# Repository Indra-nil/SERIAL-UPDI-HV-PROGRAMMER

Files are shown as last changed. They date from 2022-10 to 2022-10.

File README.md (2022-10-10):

# Serial UPDI HV Programmer
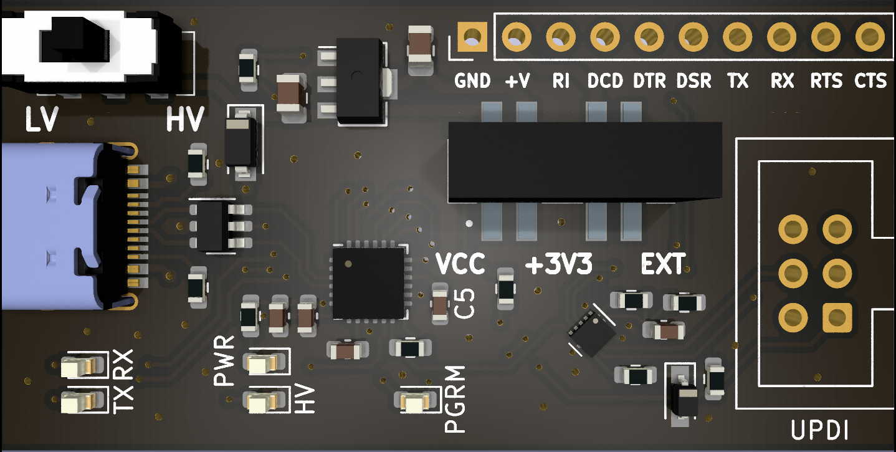
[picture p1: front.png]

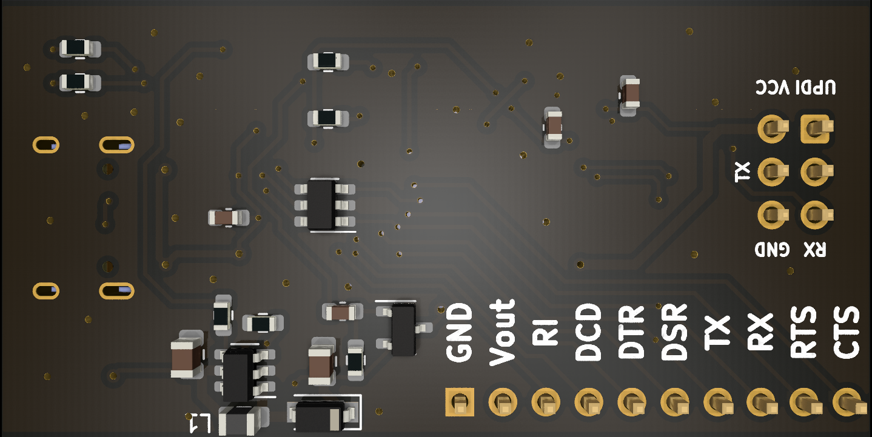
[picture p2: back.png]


Serial UPDI HV Programmer for new AVR ICs using Silabs CP2105 IC. Because of having two UART core one is dedicated to UPDI and another is for Serial communication. No need for two seperate usb port for two UART anymore.

when Vcc selected Vout nearly 4.7v

when +3.3v selected Vout 3.3v

when EXT selected Vout external voltage from target board

Some useful links
--------------------

[pyupdi](https://github.com/mraardvark/pyupdi.git)

[MegaCoreX(arduino core)](https://github.com/MCUdude/MegaCoreX.git)

[megaTinyCore(arduino core)](https://github.com/SpenceKonde/megaTinyCore.git)

[DxCore(arduino core)](https://github.com/SpenceKonde/DxCore.git)

[TinyCore(arduino core)](https://github.com/xukangmin/TinyCore.git)

[Microchip Studio for AVR](https://www.microchip.com/en-us/tools-resources/develop/microchip-studio)

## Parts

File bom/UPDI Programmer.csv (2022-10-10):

Source: | /home/indra/Documents/KiCad/UPDI Programmer/UPDI Programmer.kicad_sch
Date: | Mon 10 Oct 2022 01:49:07 PM IST
Tool: | Eeschema 6.0.6
Generator: | /app/share/kicad/plugins/bom_csv_grouped_by_value_with_fp.py
Component Count: | 51
Ref | Qnty | Value | Cmp name | Footprint | Description | Vendor
C1, C11, C13, | 3 | 1u | C | Capacitor_SMD:C_0603_1608Metric | Unpolarized capacitor
C2, C3, C9, C12, | 4 | 100n | C | Capacitor_SMD:C_0603_1608Metric | Unpolarized capacitor
C4, C7, C8, C10, | 4 | 10u | C | Capacitor_SMD:C_0805_2012Metric | Unpolarized capacitor
C5, | 1 | 4u7 | C | Capacitor_SMD:C_0603_1608Metric | Unpolarized capacitor
C6, | 1 | 10n | C | Capacitor_SMD:C_0603_1608Metric | Unpolarized capacitor
D1, D5, | 2 | 1N5819W | BAT43W-V | Diode_SMD:D_SOD-123 | 30V 0.2A Small Signal Schottky diode, SOD-123
D2, | 1 | TX | LED | LED_SMD:LED_0603_1608Metric | Light emitting diode
D3, | 1 | RX | LED | LED_SMD:LED_0603_1608Metric | Light emitting diode
D4, | 1 | PWR | LED | LED_SMD:LED_0603_1608Metric | Light emitting diode
D6, | 1 | PGRM | LED | LED_SMD:LED_0603_1608Metric | Light emitting diode
D7, | 1 | HV | LED | LED_SMD:LED_0603_1608Metric | Light emitting diode
D8, | 1 | BZT52Bxx | BZT52Bxx | Diode_SMD:D_SOD-323_HandSoldering | 500mW Zener Diode, SOD-123F
J1, | 1 | USB_C_Receptacle_USB2.0 | USB_C_Receptacle_USB2.0 | HRO_TYPE-C-31-M-12:HRO_TYPE-C-31-M-12 | USB 2.0-only Type-C Receptacle connector
J2, | 1 | UPDI | Conn_02x03_Odd_Even | Connector_IDC:IDC-Header_2x03_P2.54mm_Vertical | Generic connector, double row, 02x03, odd/even pin numbering scheme (row 1 odd numbers, row 2 even numbers), script generated (kicad-library-utils/schlib/autogen/connector/)
J3, | 1 | UART | Conn_01x10 | Connector_PinHeader_2.54mm:PinHeader_1x10_P2.54mm_Vertical | Generic connector, single row, 01x10, script generated (kicad-library-utils/schlib/autogen/connector/)
L1, | 1 | 4u7 | L | Inductor_SMD:L_0805_2012Metric | Inductor
Q1, | 1 | BSS84 | BSS84 | Package_TO_SOT_SMD:SOT-23 | -0.13A Id, -50V Vds, P-Channel MOSFET, SOT-23
R1, R4, | 2 | 4k7 | R | Resistor_SMD:R_0603_1608Metric | Resistor
R2, R3, | 2 | 5k1 | R | Resistor_SMD:R_0603_1608Metric | Resistor
R5, R13, | 2 | 10k | R | Resistor_SMD:R_0603_1608Metric | Resistor
R6, | 1 | 220 | R | Resistor_SMD:R_0603_1608Metric | Resistor
R7, R8, R9, R12, R14, R15, R16, R17, | 8 | 1k | R | Resistor_SMD:R_0603_1608Metric | Resistor
R10, | 1 | 39k | R | Resistor_SMD:R_0603_1608Metric | Resistor
R11, | 1 | 2k05 | R | Resistor_SMD:R_0603_1608Metric | Resistor
S1, | 1 | JS203011SCQN | JS203011SCQN | JS203011SCQN:JS203011SCQN
S2, | 1 | JS202011JCQN | JS202011JCQN | JS202011JCQN:JS202011JCQN
U1, | 1 | CP2105-F01-GM | CP2105-F01-GM | CP2105-F01-GM:CP2105-F01-GM
U2, | 1 | USBLC6-2SC6 | USBLC6-2SC6 | Package_TO_SOT_SMD:SOT-23-6 | Very low capacitance ESD protection diode, 2 data-line, SOT-23-6
U3, | 1 | AMS1117-3.3 | AMS1117-3.3 | Package_TO_SOT_SMD:SOT-89-3 | 1A Low Dropout regulator, positive, 3.3V fixed output, SOT-223
U4, | 1 | 74LVC2G04DVBR | 74LVC2G04 | Package_TO_SOT_SMD:SOT-23-6 | Dual NOT Gate, Low-Voltage CMOS
U5, | 1 | MT3608 | MT3608 | Package_TO_SOT_SMD:SOT-23-6 | High Efficiency 1.2MHz 2A Step Up Converter, 2-24V Vin, 28V Vout, 4A current limit, 1.2MHz, SOT23-6
U6, | 1 | TXB0104RUT | TXB0104RUT | Package_DFN_QFN:Texas_R_PUQFN-N12 | 4-Bit Bidirectional Voltage-Level Translator, Auto Direction Sensing and ±15-kV ESD Protection, 1.2 - 3.6V APort, 1.65 - 5.5V BPort, Texas_PUQFN-12

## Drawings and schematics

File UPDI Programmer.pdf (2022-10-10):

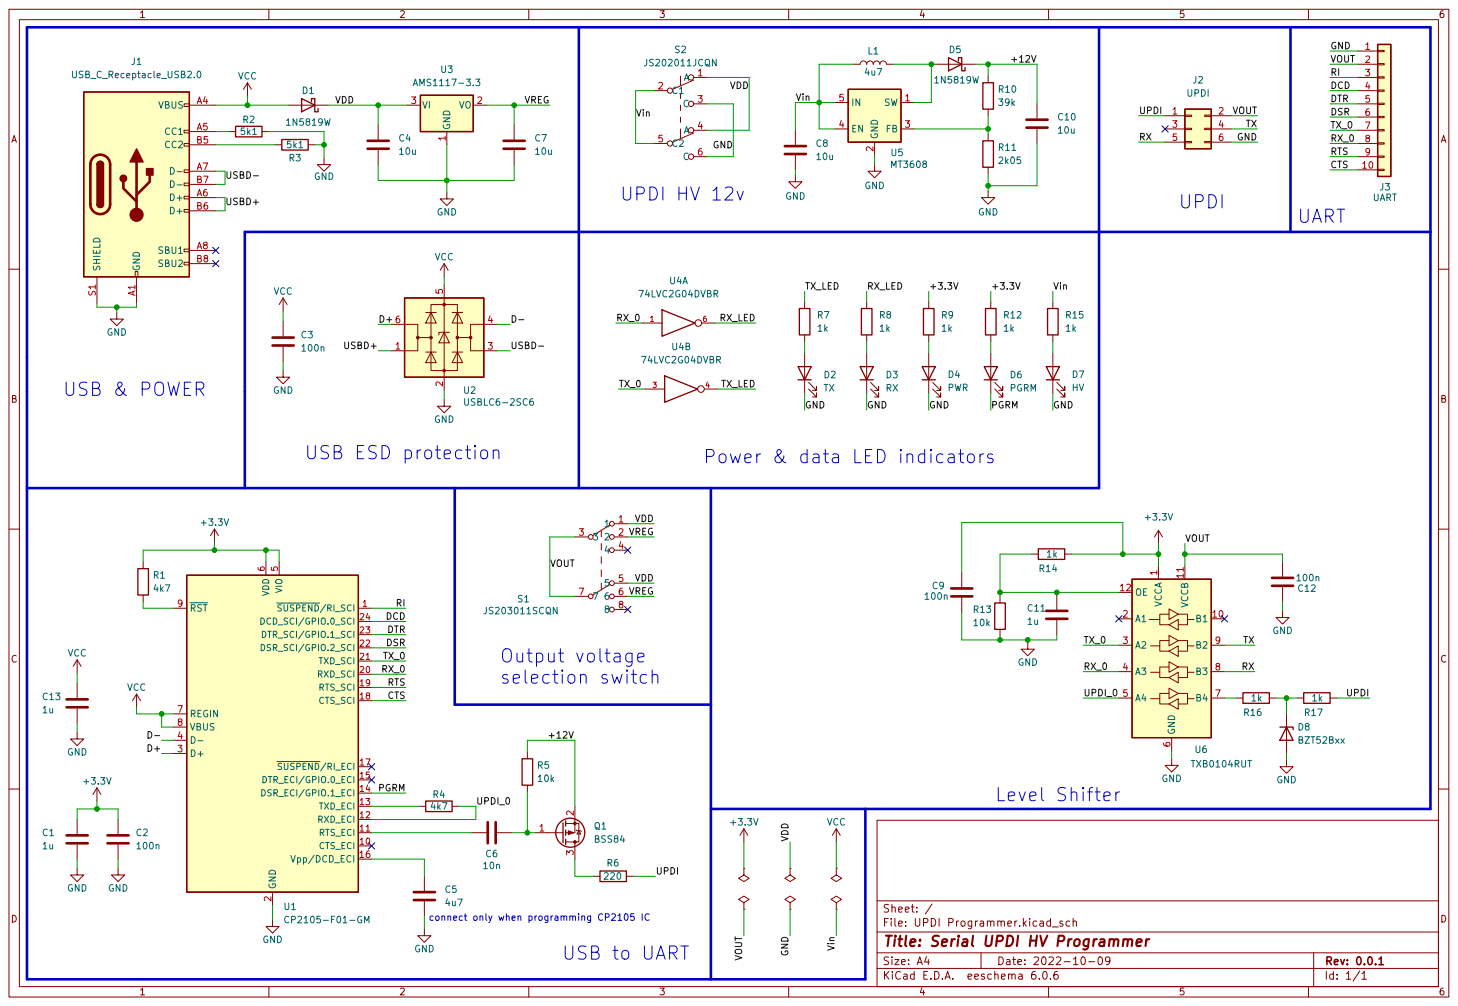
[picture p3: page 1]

Power & data LED indicators

6 REGIN 7 VBUS 8 ~{RST} 9 U1CP2105-F01-GM

2 RXD_SCI 20 TXD_SCI 21 DSR_SCI/GPIO.2_SCI 22 DTR_SCI/GPIO.1_SCI 23 DCD_SCI/GPIO.0_SCI 24 D+ 3 D- 4 VIO

File: UPDI Programmer.kicad_sch Sheet: /
Id: 1/1 Title: Serial UPDI HV Programmer

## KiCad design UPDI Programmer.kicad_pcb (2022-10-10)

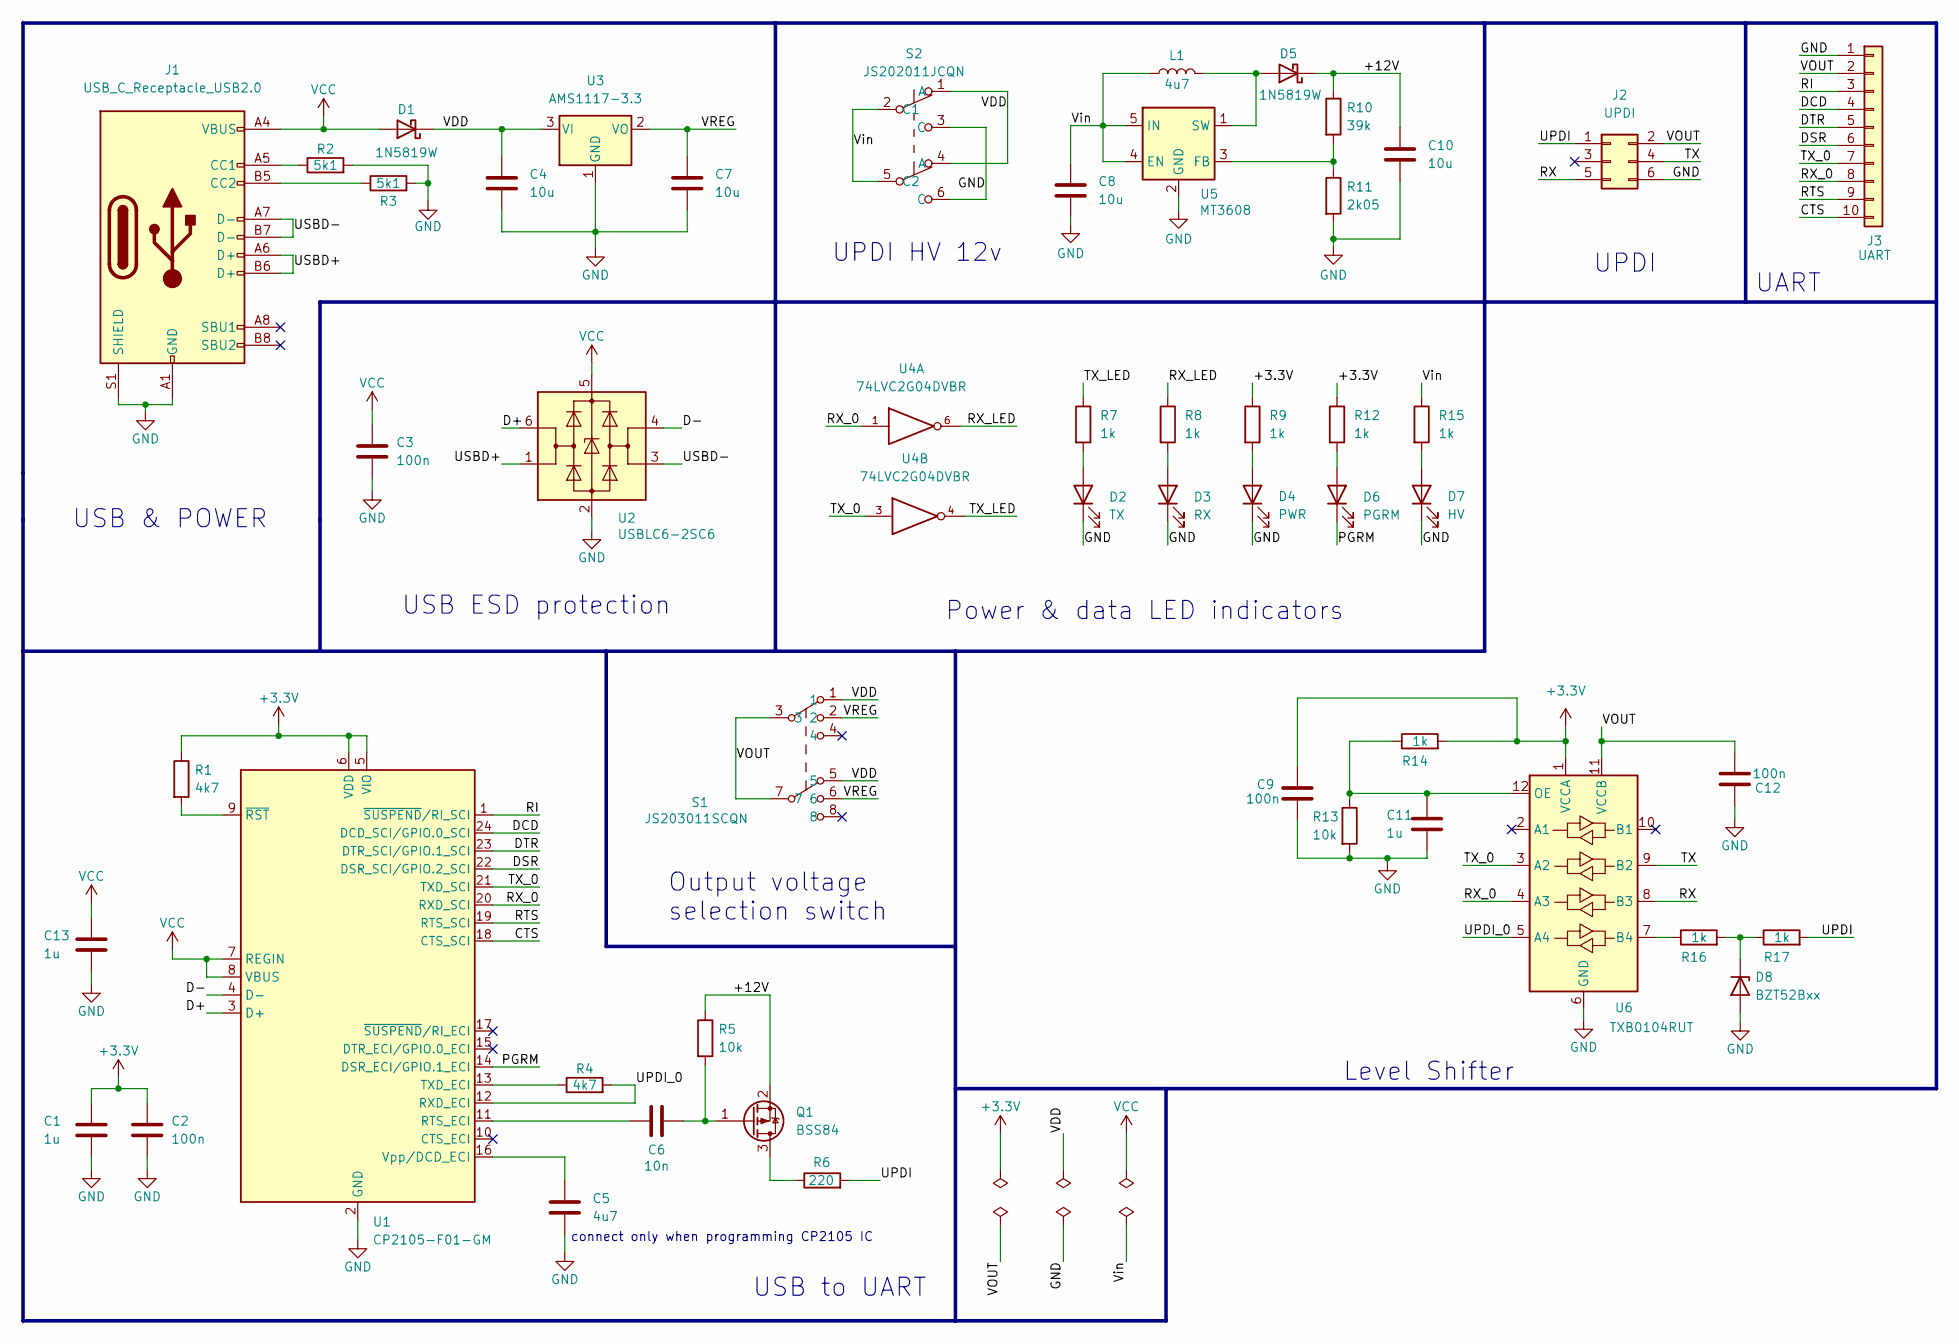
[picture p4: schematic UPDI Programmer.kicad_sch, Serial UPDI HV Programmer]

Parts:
C1, C11, C13: 1u; C_0603_1608Metric
C2, C3, C9, C12: 100n; C_0603_1608Metric
C4, C7, C8, C10: 10u; C_0805_2012Metric
C5: 4u7; C_0603_1608Metric
C6: 10n; C_0603_1608Metric
D1, D5: 1N5819W; D_SOD-123
D2: TX; LED_0603_1608Metric
D3: RX; LED_0603_1608Metric
D4: PWR; LED_0603_1608Metric
D6: PGRM; LED_0603_1608Metric
D7: HV; LED_0603_1608Metric
D8: BZT52Bxx; D_SOD-323_HandSoldering
J1: USB_C_Receptacle_USB2.0; HRO_TYPE-C-31-M-12
J2: UPDI; IDC-Header_2x03_P2.54mm_Vertical
J3: UART; PinHeader_1x10_P2.54mm_Vertical
L1: 4u7; L_0805_2012Metric
Q1: BSS84; SOT-23
R1, R4: 4k7; R_0603_1608Metric
R2, R3: 5k1; R_0603_1608Metric
R5, R13: 10k; R_0603_1608Metric
R6: 220; R_0603_1608Metric
R7, R8, R9, R12, R14, R15, R16, R17: 1k; R_0603_1608Metric
R10: 39k; R_0603_1608Metric
R11: 2k05; R_0603_1608Metric
S1: JS203011SCQN; Manufacturer_Part_Number JS203011SCQN; Mouser Part Number 611-JS203011SCQN
S2: JS202011JCQN; Manufacturer_Part_Number JS202011JCQN; Mouser Part Number 611-JS202011JCQN
U1: CP2105-F01-GM; Manufacturer_Part_Number CP2105-F01-GM
U2: USBLC6-2SC6; SOT-23-6
U3: AMS1117-3.3; SOT-89-3
U4: 74LVC2G04DVBR; SOT-23-6
U5: MT3608; SOT-23-6
U6: TXB0104RUT; Texas_R_PUQFN-N12

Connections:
+3.3V: C1.1, C2.1, C9.2, R1.1, R9.1, R12.1, R14.2, U1.5 (VIO), U1.6 (VDD), U6.1 (VCCA)
/+12V: C10.1, D5.1 (K), Q1.2 (S), R5.1, R10.1
/CTS: J3.10, U1.18 (CTS_SCI)
/D+: U1.3 (D+), U2.6 (I/O1)
/D-: U1.4 (D-), U2.4 (I/O2)
/DCD: J3.4, U1.24 (DCD_SCI/GPIO.0_SCI)
/DSR: J3.6, U1.22 (DSR_SCI/GPIO.2_SCI)
/DTR: J3.5, U1.23 (DTR_SCI/GPIO.1_SCI)
/PGRM: D6.1 (K), U1.14 (DSR_ECI/GPIO.1_ECI)
/RI: J3.3, U1.1 (~SUSPEND/RI_SCI)
/RTS: J3.9, U1.19 (RTS_SCI)
/RX: J2.5, U6.8 (B3)
/RX_0: J3.8, U1.20 (RXD_SCI), U4.1, U6.4 (A3)
/RX_LED: R8.1, U4.6
/TX: J2.4, U6.9 (B2)
/TX_0: J3.7, U1.21 (TXD_SCI), U4.3, U6.3 (A2)
/TX_LED: R7.1, U4.4
/UPDI: J2.1, R6.2, R17.2
/UPDI_0: R4.2, U1.12 (RXD_ECI), U6.5 (A4)
/USBD+: J1.A6 (D+), J1.B6 (D+), U2.1 (I/O1)
/USBD-: J1.A7 (D-), J1.B7 (D-), U2.3 (I/O2)
/VDD: C4.1, D1.1 (K), S1.1, S1.5, S2.1 (A), S2.4 (A), U3.3 (VI)
/VOUT: C12.1, J2.2, J3.2, S1.3, S1.7, U6.11 (VCCB)
/VREG: C7.1, S1.2, S1.6, U3.2 (VO)
/Vin: C8.1, L1.1, R15.1, S2.2 (C1), S2.5 (C2), U5.4 (EN), U5.5 (IN)
GND: C1.2, C2.2, C3.2, C4.2, C5.2, C7.2, C8.2, C9.1, C10.2, C11.1, C12.2, C13.2, D2.1 (K), D3.1 (K), D4.1 (K), D7.1 (K), D8.2 (A), J1.A1 (GND), J1.A12 (GND), J1.B1 (GND), J1.B12 (GND), J1.S1 (SHIELD), J2.6, J3.1, R2.2, R3.2, R11.2, R13.2, S2.3 (C), S2.6 (C), U1.2 (GND), U1.25 (GND), U2.2 (GND), U3.1 (GND), U4.2 (GND), U5.2 (GND), U6.6 (GND)
unnamed: C5.1, U1.16 (Vpp/DCD_ECI)
unnamed: C6.1, U1.11 (RTS_ECI)
unnamed: C6.2, Q1.1 (G), R5.2
unnamed: C11.2, R13.1, R14.1, U6.12 (OE)
unnamed: D2.2 (A), R7.2
unnamed: D3.2 (A), R8.2
unnamed: D4.2 (A), R9.2
unnamed: D5.2 (A), L1.2, U5.1 (SW)
unnamed: D6.2 (A), R12.2
unnamed: D7.2 (A), R15.2
unnamed: D8.1 (K), R16.2, R17.1
unnamed: J1.A5 (CC1), R2.1
unnamed: J1.B5 (CC2), R3.1
unnamed: Q1.3 (D), R6.1
unnamed: R1.2, U1.9 (~RST)
unnamed: R4.1, U1.13 (TXD_ECI)
unnamed: R10.2, R11.1, U5.3 (FB)
unnamed: R16.1, U6.7 (B4)
VCC: C3.1, C13.1, D1.2 (A), J1.A4 (VBUS), J1.A9 (VBUS), J1.B4 (VBUS), J1.B9 (VBUS), U1.7 (REGIN), U1.8 (VBUS), U2.5 (VBUS), U4.5 (VCC)

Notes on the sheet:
Output voltage selection switch
Level Shifter
USB to UART
UPDI HV 12v
UART
connect only when programming CP2105 IC
USB ESD protection
UPDI
Power & data LED indicators
USB & POWER

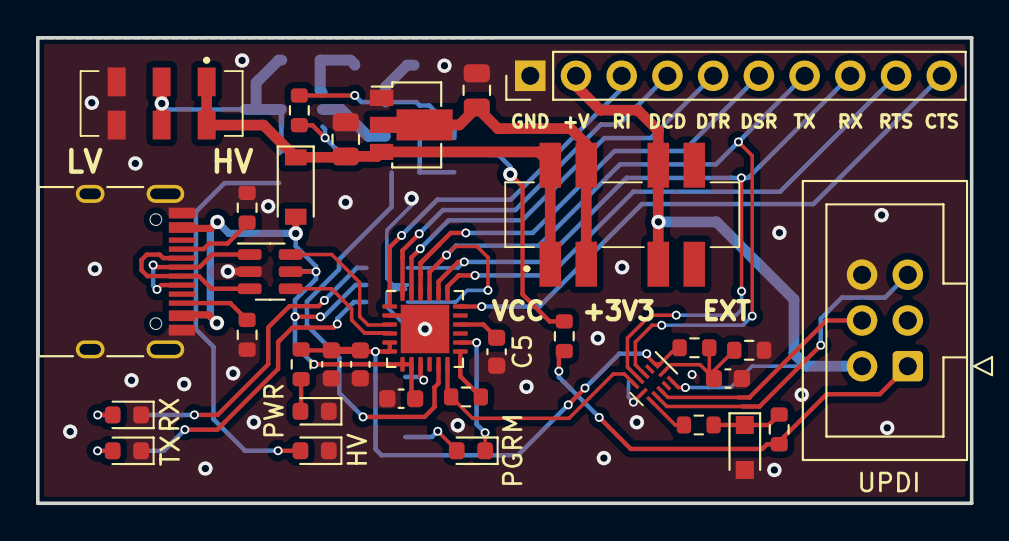
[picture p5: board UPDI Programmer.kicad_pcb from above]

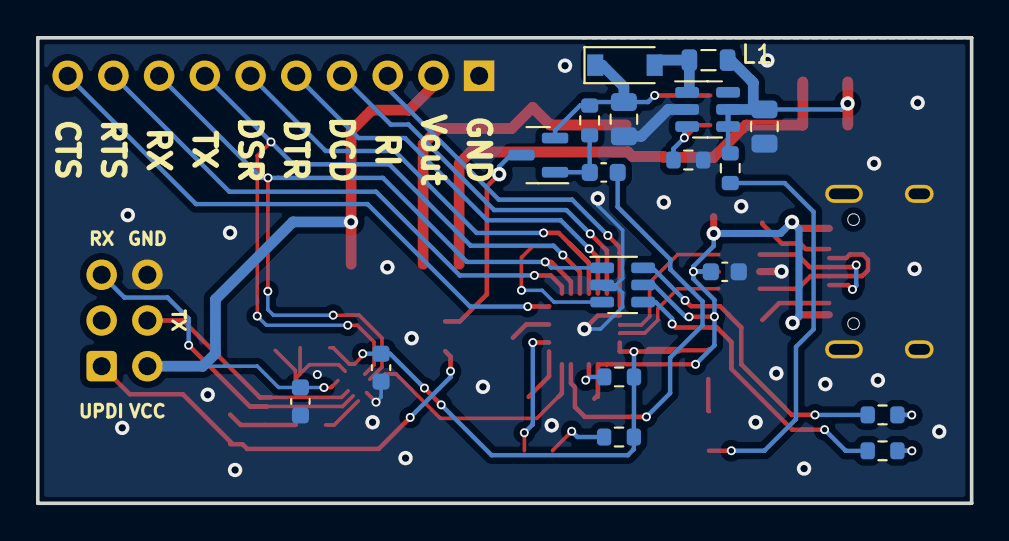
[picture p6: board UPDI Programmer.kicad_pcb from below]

Board: 2 copper layers, 51.9 x 25.9 mm, 51 parts (18 on the bottom side), 45 nets.
